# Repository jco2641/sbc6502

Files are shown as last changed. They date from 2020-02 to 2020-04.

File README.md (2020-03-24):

# sbc6502
A 65C02 based single board computer

Credits
- Ben Eater 6502 videos
- https://github.com/dbuchwald/6502/
- http://sbc.rictor.org/decoder.html
- Tons of other 6502 info pages and projects

## Development Environment in Windows
- Git 
  - Either git for windows, or in cygwin environment
- Latest Cygwin 
  - https://cygwin.com/setup-x86_64.exe
- Select Additional Cygwin Packages during install
  - gcc
  - make
  - pkg-config
  - xxd
- CC65 windows nightly snapshot 
  - https://sourceforge.net/projects/cc65/files/cc65-snapshot-win32.zip/download
  - extract zip file to a folder
- Build minipro from source (via git)
  - https://gitlab.com/DavidGriffith/minipro.git
  - cd minipro
  - run make, there will be warnings but it will build
- Add entries to path for locations of minipro and cc65/bin folder

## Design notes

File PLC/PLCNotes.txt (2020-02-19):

Starting point for PLC design idea:
http://sbc.rictor.org/decoder.html

This site and page have been linked in discussions a few times.
PLCs are a way to implement complex combinational logic that would ordinarily take tens of logic gates in a single IC.
So I decided to try it.

What I got - Software:
WinCUPL: https://www.microchip.com/design-centers/fpgas-and-plds/splds-cplds/pld-design-resources
Serial number from download page: 60008009
WinCUPL Manual:  http://ww1.microchip.com/downloads/en/DeviceDoc/doc0737.pdf

Hardware:
22V10 PLD array:  https://www.jameco.com/webapp/wcs/stores/servlet/ProductDisplay?productId=39159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
Programmer: I used my TL866II Plus, and the Xgpro software (windows) that came with it.  It looks like the minipro command line also supports writing to PLCs

I've decided to use all 32K of RAM, and take the 64 bytes for 4 VIAs from the low end of ROM.
The memory map I came up with:  https://docs.google.com/spreadsheets/d/1dtwUZS-A5DAV1TVMrngq8Xj7K0klu_qNPEEbwgagwu0/edit?usp=sharing

CUPL source for memory map
CUPL simulator input
CUPL simulator output
Screenshot of simulator output in comment
Arduino chip validator source
Screenshot of validator output in comment
https://gist.github.com/jco2641/1146407eb2ec3f7b878f308369b9e9a2

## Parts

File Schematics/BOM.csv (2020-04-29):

Designator | Name | Quantity | Footprint
C1 | 1000uF | 1 | CAP-D10.0XF5.0
C2,C3,C4,C5,C6,C7,C8,C9,C10,C11 | 0.1uF | 10 | RAD-0.2
C12,C13 | 47pF | 2 | RAD-0.2
LED1 | TX | 1 | LED-3MM/2.54
LED2 | RX | 1 | LED-3MM/2.54
R1,R2,R7 | 3K3 | 2 | AXIAL-0.4
R3,R4 | 270R | 2 | AXIAL-0.4
R5,R6 | 27R | 2 | AXIAL-0.4
SW1 | Reset | 1 | KEY-6.0*6.0-2
U1 | W65C02SP | 1 | DIP-40_W15.24MM_SOCKET_LONGPADS
U2 | 28C256 | 1 | DIP-28_W15.24MM_SOCKET_LONGPADS
U3 | 62256 | 1 | DIP-28_W15.24MM_SOCKET_LONGPADS
U4 | GAL22V10 | 1 | DIP-24_W7.62MM_SOCKET_LONGPADS
U5 | 74HC21 | 1 | DIP-14_W7.62MM_SOCKET_LONGPADS
U6 | DS1813-10 | 1 | TO92-INLINE
U7 | R6551_ACIA | 1 | DIP-28_W15.24MM_SOCKET_LONGPADS
U8 | FT230XS-U | 1 | SSOP-16_L5.0-W4.4-P0.65-LS6.4-BL
U9,U10 | W65C22 | 2 | DIP-40_W15.24MM_SOCKET_LONGPADS
USB1 | USB-B-S-RA | 1 | PKG-USB-B-S-RA
X1 | 1 MHZ | 1 | OSCILLATOR_DIP-14
X2 | 1.8432 MHZ | 1 | OSCILLATOR_DIP-14

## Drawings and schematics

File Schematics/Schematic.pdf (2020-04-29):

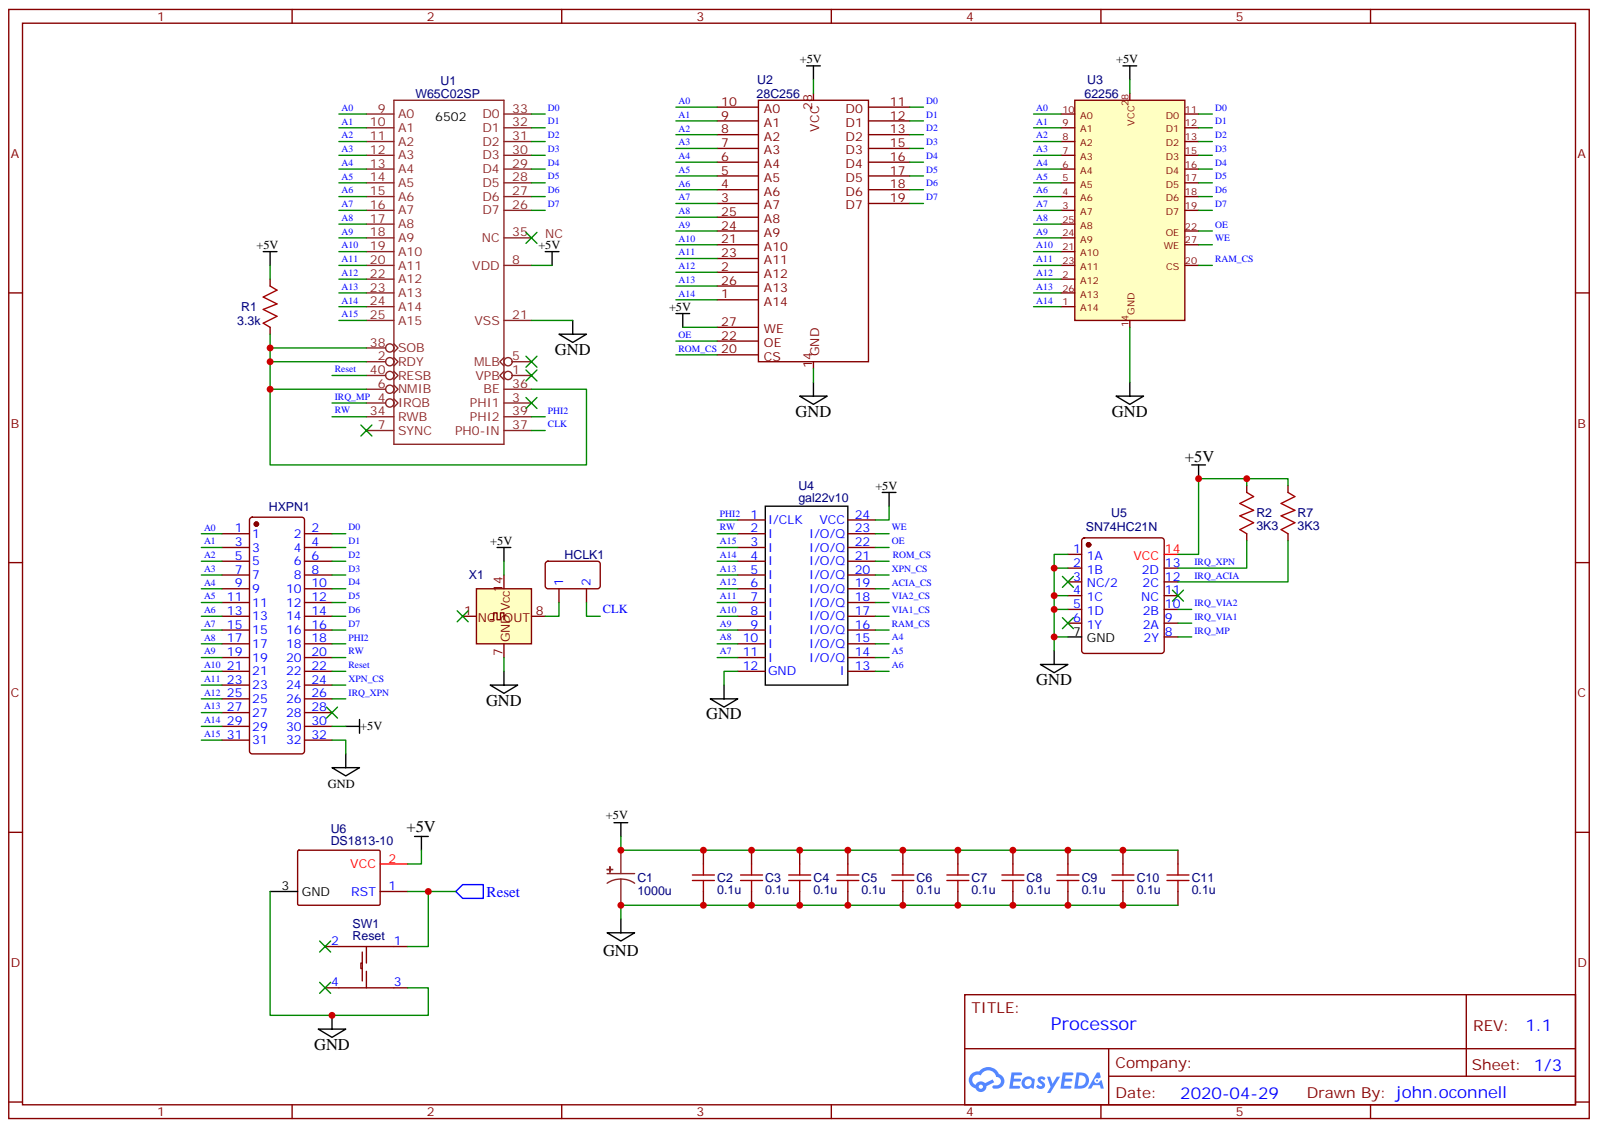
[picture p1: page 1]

Drawn By: john.oconnell

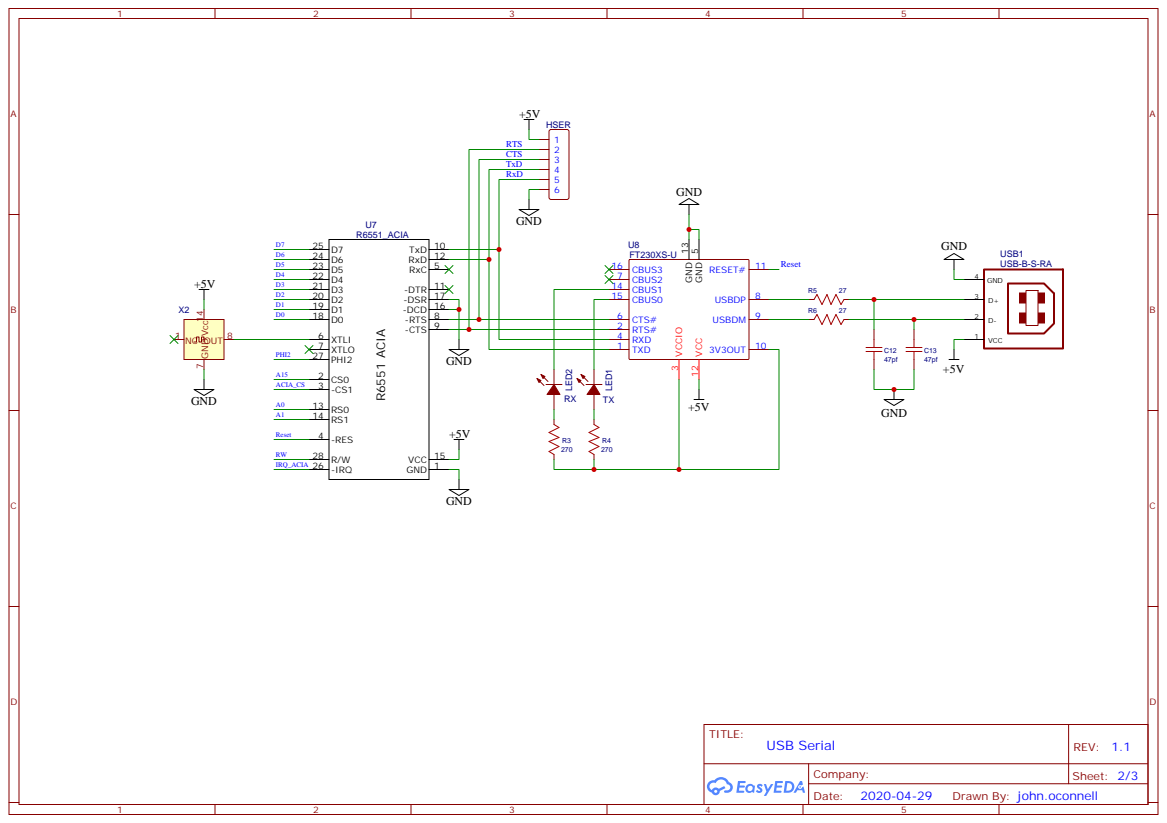
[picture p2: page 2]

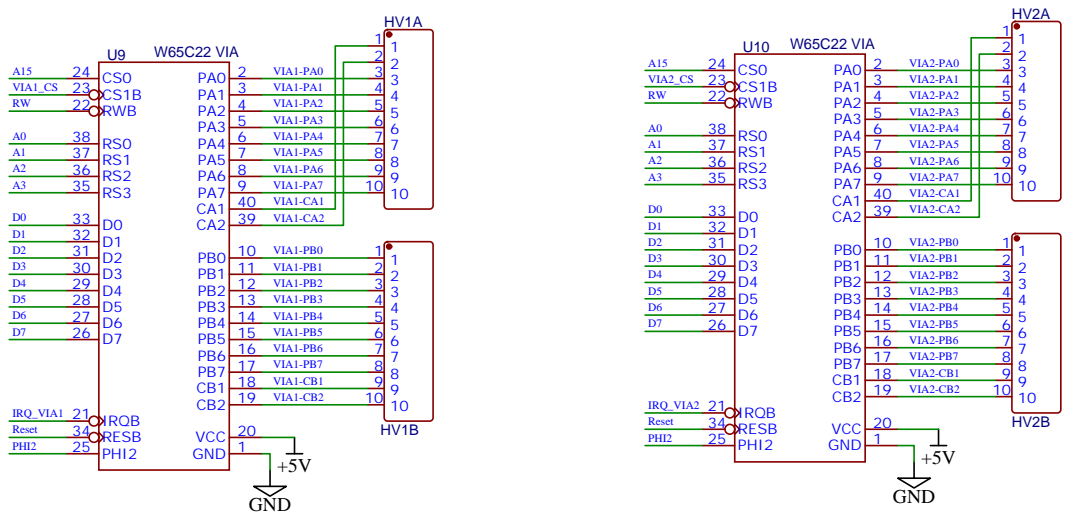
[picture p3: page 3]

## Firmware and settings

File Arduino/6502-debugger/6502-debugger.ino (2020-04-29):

#include <Arduino.h>
#include <stdio.h>

/* 
  Based on original by Ben Eater https://eater.net/6502/
  Opcode decoding credit to: https://github.com/dpm-343/6502-monitor/blob/master/6502-monitor.ino 
*/

// Address & data pin connections - pin order below is MSB to LSB
// Values are collected by adding with left shift in order of defined array
const char ADDR[] = {22, 24, 26, 28, 30, 32, 34, 36, 38, 40, 42, 44, 46, 48, 50, 52};
// Address 65C02 pins 25 .. 22, 20 .. 9
// Data 65C02 pins 26 .. 33
const char DATA[] = {39, 41, 43, 45, 47, 49, 51, 53};
const char opcodeMatrix[256][5] = {
             "BRK", "ORA", ""   , "", "TSB", "ORA", "ASL", "RMB0", "PHP", "ORA", "ASL", ""   , "TSB", "ORA", "ASL", "BBR0",
             "BPL", "ORA", "ORA", "", "TRB", "ORA", "ASL", "RMB1", "CLC", "ORA", "INC", ""   , "TRB", "ORA", "ASL", "BBR1",
             "JSR", "AND", ""   , "", "BIT", "AND", "ROL", "RMB2", "PLP", "AND", "ROL", ""   , "BIT", "AND", "ROL", "BBR2",
             "BMI", "AND", "AND", "", "BIT", "AND", "ROL", "RMB3", "SEC", "AND", "DEC", ""   , "BIT", "AND", "ROL", "BBR3",
             "RTI", "EOR", ""   , "", ""   , "EOR", "LSR", "RMB4", "PHA", "EOR", "LSR", ""   , "JMP", "EOR", "LSR", "BBR4",
             "BVC", "EOR", "EOR", "", ""   , "EOR", "LSR", "RMB5", "CLI", "EOR", "PHY", ""   , ""   , "EOR", "LSR", "BBR5",
             "RTS", "ADC", ""   , "", "STZ", "ADC", "ROR", "RMB6", "PLA", "ADC", "ROR", ""   , "JMP", "ADC", "ROR", "BBR6",
             "BVS", "ADC", "ADC", "", "STZ", "ADC", "ROR", "RMB7", "SEI", "ADC", "PLY", ""   , "JMP", "ADC", "ROR", "BBR7",
             "BRA", "STA", ""   , "", "STY", "STA", "STX", "SMB0", "DEY", "BIT", "TXA", ""   , "STY", "STA", "STX", "BBS0",
             "BCC", "STA", "STA", "", "STY", "STA", "STX", "SMB1", "TYA", "STA", "TXS", ""   , "STZ", "STA", "STZ", "BBS1",
             "LDY", "LDA", "LDX", "", "LDY", "LDA", "LDX", "SMB2", "TAY", "LDA", "TAX", ""   , "LDY", "LDA", "LDX", "BBS2",
             "BCS", "LDA", "LDA", "", "LDY", "LDA", "LDX", "SMB3", "CLV", "LDA", "TSX", ""   , "LDY", "LDA", "LDX", "BBS3",
             "CPY", "CMP", ""   , "", "CPY", "CMP", "DEC", "SMB4", "INY", "CMP", "DEX", "WAI", "CPY", "CMP", "DEC", "BBS4",
             "BNE", "CMP", "CMP", "", ""   , "CMP", "DEC", "SMB5", "CLD", "CMP", "PHX", "STP", ""   , "CMP", "DEC", "BBS5",
             "CPX", "SBC", ""   , "", "CPX", "SBC", "INC", "SMB6", "INX", "SBC", "NOP", ""   , "CPX", "SBC", "INC", "BBS6",
             "BEQ", "SBC", "SBC", "", ""   , "SBC", "INC", "SMB7", "SED", "SBC", "PLX", ""   , ""   , "SBC", "INC", "BBS7"
            };

                        // 65C02 Pin number
#define CLOCK       2   // 37 or 39
#define READ_WRITE  3   // 34
#define IRQ         4   // 4
#define NMI         5   // 6
#define SYNC        6   // 7

void setup() {
  for (int n = 0; n < 16; n += 1) {
    pinMode(ADDR[n], INPUT);
  }
  for (int n = 0; n < 8; n += 1) {
    pinMode(DATA[n], INPUT);
  }
  pinMode(CLOCK, INPUT);
  pinMode(READ_WRITE, INPUT);
  pinMode(IRQ, INPUT);
  pinMode(NMI, INPUT);
  pinMode(SYNC, INPUT);

  attachInterrupt(digitalPinToInterrupt(CLOCK), onClock, RISING);
  
  Serial.begin(57600);
}

void onClock() {
  char output[60];

  unsigned int address = 0;
  for (int n = 0; n < 16; n += 1) {
    int bit = digitalRead(ADDR[n]) ? 1 : 0;
    address = (address << 1) + bit;
  }
 
  unsigned int data = 0;
  for (int n = 0; n < 8; n += 1) {
    int bit = digitalRead(DATA[n]) ? 1 : 0;
    data = (data << 1) + bit;
  }

  sprintf(output, "Addr: %04x R/W: %c IRQ: %c NMI: %c Data: %02x  %4s",
          address, 
          digitalRead(READ_WRITE) ? 'r' : 'W',
          digitalRead(IRQ) ? 'H' : 'L',
          digitalRead(NMI) ? 'H' : 'L',
          data,
          digitalRead(SYNC) ?  opcodeMatrix[data] : "  "
        );
  Serial.println(output);
}

void loop() {
}

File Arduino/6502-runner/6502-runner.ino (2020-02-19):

const char ADDR[] = {22, 24, 26, 28, 30, 32, 34, 36, 38, 40, 42, 44, 46, 48, 50, 52};
const char DATA[] = {39, 41, 43, 45, 47, 49, 51, 53};

#define CLOCK 2
#define READ_WRITE 3
#define RESET 4

#define MICRODELAY 50
#define MILLIDELAY 50
// Microseconds delay per clock level.
// Double this value for period.
// Take reciprocal of period for frequency.
// 25 us = 20kHz
// 50 us = 10kHz
// 100 us = 5 kHz
// 1000 us = 500 Hz
// 5000 us = 100 Hz
// For slower replace delayMicroseconds() with delay() for milliseconds
// 100 ms = 10 Hz

void setup() {
  for (int i = 0; i < 16; i++) {
    pinMode(ADDR[i], INPUT);
  }
  for (int i = 0; i < 8; i++) {
    pinMode(DATA[i], INPUT);
  }
  pinMode(CLOCK, OUTPUT);
  pinMode(READ_WRITE, INPUT);
  pinMode(RESET, OUTPUT);
  digitalWrite(RESET, HIGH);

  Serial.begin(230400);
  while (!Serial) {
    ; // Wait for serial monitor to get opened and established
  }
  Serial.println("Enter a number of clock cycles to run, 0 to reset.");
}

void printPins() {
  char output[15];

  unsigned int address = 0;
  for (int i = 0; i < 16; i++) {
    int bit = digitalRead(ADDR[i]) ? 1 : 0;
    Serial.print(bit);
    address = (address << 1) + bit;
  }

  Serial.print("   ");

  unsigned int data = 0;
  for (int i = 0; i < 8; i++) {
    int bit = digitalRead(DATA[i]) ? 1 : 0;
    Serial.print(bit);
    data = (data << 1) + bit;
  }

  sprintf(output, "  %04x   %c   %02x", address, digitalRead(READ_WRITE) ? 'r' : 'W', data);
  Serial.println(output);
  if (address >= 0x8000 && address <= 0x800F) {
    Serial.println("");
  }
}

void clockPulse(bool print) {
  digitalWrite(CLOCK, HIGH);
  //delayMicroseconds(MICRODELAY);
  delay(MILLIDELAY);
  if (print)
    printPins();
  digitalWrite(CLOCK, LOW);
  //delayMicroseconds(MICRODELAY);
  delay(MILLIDELAY);
}

void doReset() {
  Serial.println("Resetting");
  // set reset pin
  digitalWrite(RESET, LOW);
  //two clock cycles
  clockPulse(false);
  clockPulse(false);
  // clear reset pin
  digitalWrite(RESET, HIGH);
  //init cycle 9 clocks until pc is set
  for (int i = 0; i < 9; i++) {
    clockPulse(true);
  }
}

void serialEvent() {
  int cycles = Serial.parseInt();

  if (cycles == 0) {
    doReset();
  } else {
    char output[15];
    sprintf(output, "Running %d cycles", cycles);
    Serial.println(output);
    for (int i = 0; i < cycles; i++) {
      clockPulse(false);
    }
  }
  Serial.println("Enter a number of clock cycles to run, 0 to reset.");
}

void loop() {
}

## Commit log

2020-02-19 Initial repository
    [firmware.cfg]
2020-02-19 Basic VIA, Blink some LEDs
    [firmware.cfg]
2020-02-19 Second demo program for LEDs
2020-03-12 Add Kicad stuff
    [SBC6502.kicad_pcb, SBC6502.sch]
2020-03-22 Remove kicad stuff
    [SBC6502.kicad_pcb, SBC6502.sch]
2020-04-01 schematics for rev 1.0
    [BOM.csv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]
2020-04-18 Remove debug leds from lcd4
2020-04-29 Interrupt testing program
2020-04-29 Enhanced arduino monitor program
2020-04-29 Interrupt testing on fast clock with LCD
2020-04-29 Schematic and PCB revision 1.1
    [BOM.csv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]
